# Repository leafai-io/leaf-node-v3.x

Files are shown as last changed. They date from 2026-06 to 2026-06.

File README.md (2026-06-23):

# Leaf Node 3.1

Leaf AI is an independent, open-source project. If you find it useful, you can support its continued development at [Leaf AI Support](https://leafai.io/support.html).

The Leaf Node is an open-source environmental 
monitoring and control device built on the 
ESP32-S3. It reads sensor data, publishes it 
over MQTT, and can trigger actuators — allowing 
you to monitor conditions and directly control 
connected devices such as lights, fans, pumps 
and valves. Configuration is handled wirelessly 
via BLE, making it a self-contained building 
block for precision agriculture and 
environmental monitoring and automation systems.

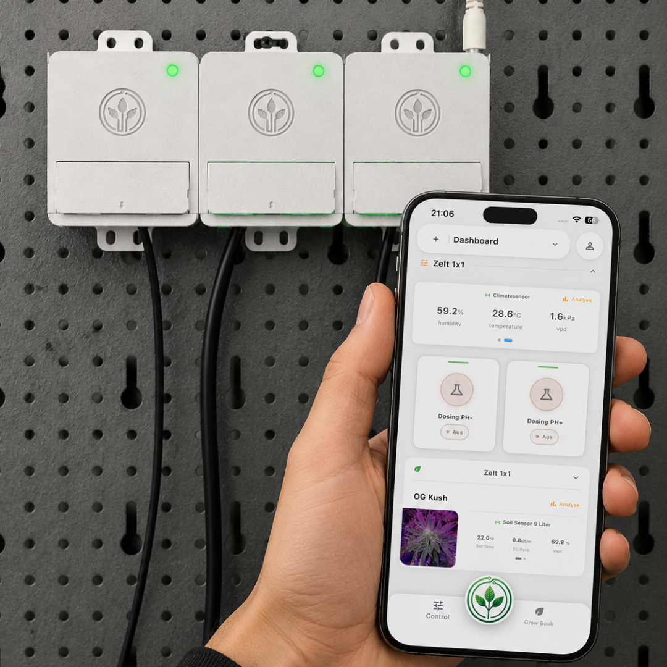
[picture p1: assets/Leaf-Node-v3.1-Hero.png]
Leaf Node


<!-- Hero image: replace the path below with your device photo -->
<!-- ![Leaf Node device photo](assets/hero.jpg) -->

---

## Philosophy

Leaf Node is built around one principle: **it should just work.** From first flash to live sensor data in minutes — simple enough for a grower to deploy in the field, open enough for a developer to extend and build on. No unnecessary complexity, no steep learning curve.

---

## Features

- **Multi-protocol sensor support** — I2C, RS485, SDI-12, OneWire on a single board
- **MQTT telemetry** — publishes sensor data and heartbeats, receives commands
- **OTA firmware updates** — triggered via MQTT command, no physical access needed
- **BLE provisioning** — initial Wi-Fi and MQTT setup from the companion app, no serial cable required
- **Scheduling** — DAC and actuator outputs can be programmed on a time-based schedule
- **Smart control** — MOSFET and relay outputs with duration-based switching
- **Node chaining** — UART-based daisy-chain for multi-node deployments
- **Watchdog & health monitoring** — automatic recovery with exponential backoff on sensor errors
- **Factory mode** — serial-console provisioning for production flashing

---

## Hardware

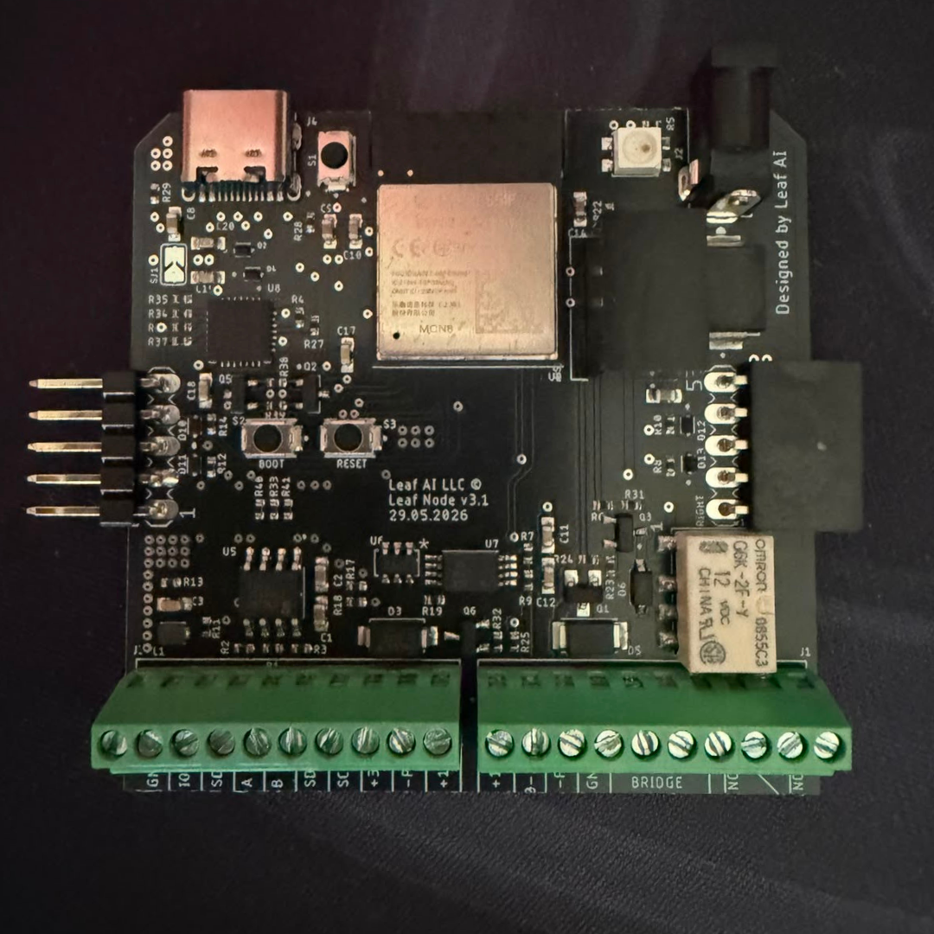
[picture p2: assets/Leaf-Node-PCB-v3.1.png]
Leaf Node PCB


### Overview

| Component | Details |
|---|---|
| MCU | ESP32-S3 |
| Status LED | WS2812B addressable RGB (v3) |
| RS485 | Half-duplex, DE/RE controlled |
| I2C | SDA GPIO8, SCL GPIO9 |
| SDI-12 | GPIO12 (shared with OneWire via hardware bridge) |
| OneWire | GPIO12 |
| Actuators | MOSFET (GPIO36), Relay (GPIO38), DAC (MCP4725 via I2C) |
| PWM | GPIO2 (1 kHz, 10-bit) + MOSFET gate (5 kHz, 10-bit) |

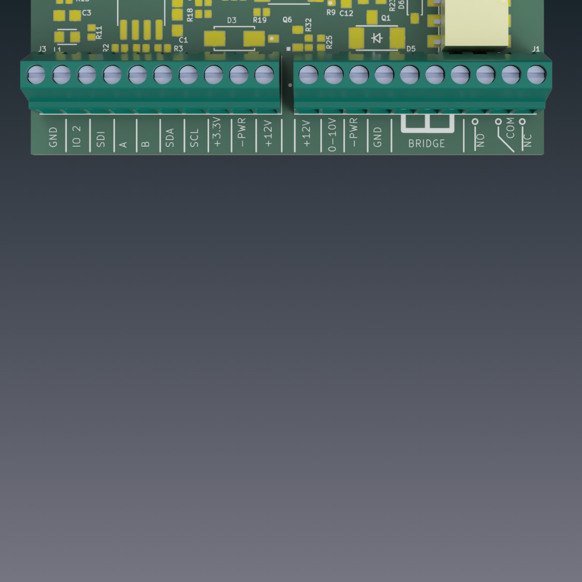
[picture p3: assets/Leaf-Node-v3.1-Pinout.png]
Leaf Node Pinout


### Supported Sensors

| Sensor | Interface | Wiring | Measurement |
|---|---|---|---|
| SHT31  | I2C (0x44) | +3.3V · GND · SDA · SCL | Temperature, Humidity |
| EZO pH | I2C (0x63) | +3.3V · GND · SDA · SCL | pH |
| EZO EC | I2C (0x64) | +3.3V · GND · SDA · SCL | Electrical Conductivity |
| TEROS 12 | SDI-12 | +3.3V · GND · SDI-12 | Soil moisture, temperature, EC |
| DS18B20 | OneWire | +3.3V · GND · Need Modification | Temperature |
| SLT5007 | RS485 | +3.3V · GND · A · B | VWC, Bulk EC, Soil temperature, Pore EC |
| CWT-PSS | RS485 | +12V · GND · A · B | PAR (Photosynthetically Active Radiation) |
| LEAFTHSN | RS485 | +12V · GND · A · B | Leaf wetness, Leaf temperature |
| CWT-SoilTHS | RS485 | +12V · GND · A · B | VWC, Soil temperature |
| CWT-THXXS | RS485 | +12V · GND · A · B | Air temperature, Humidity, VPD |

### Actuators

| Actuator | GPIO / Interface | Wiring | Typical Use |
|---|---|---|---|
| MOSFET | GPIO36 | +12V · -PWR | Pumps, fans, DC loads |
| Relay | GPIO38 | COM · NO · NC | AC/DC switching, high-current loads |
| DAC (MCP4725) | I2C (0x60) | 0-10V · GND | Analog 0–5 V output (e.g. dosing pumps) |
| PWM | GPIO2 | IO2 · GND | Variable speed / dimming control |

### PCB & Enclosure

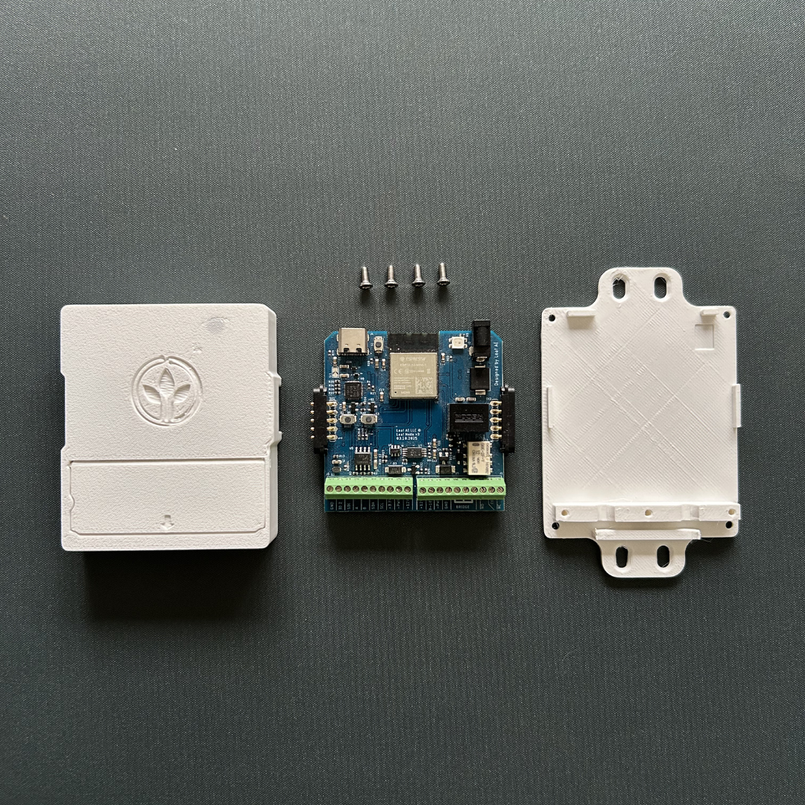
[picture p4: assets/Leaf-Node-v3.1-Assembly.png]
Leaf Node Assembly


- KiCad project: [hardware/pcb/kiCad/](hardware/pcb/kiCad/)
- Enclosure STL/STEP files: [hardware/enclosure/](hardware/enclosure/)
---

## Getting Started

### Option A — Web Flasher (recommended)

No toolchain required. Works directly in Chrome/Edge.

1. **Get the hardware** — order a ready-to-use Leaf Node at [Build Your Leaf Node](https://leafai.io/build-node.html), or fabricate your own PCB from the [KiCad files](hardware/pcb/kiCad/)
2. Open the **[Leaf AI Firmware Flasher](https://leafai.io/firmware-flasher.html)** and follow the on-screen steps
3. Open the Leaf AI app, tap **Add Device**, and provision Wi-Fi via BLE

That's it — the node connects to the Leaf AI backend and starts publishing sensor data.

> A free Leaf AI account is required to use the app. Sign up directly in the Leaf AI app.

---

### Option B — Build from source (PlatformIO)

For developers who want to modify or extend the firmware.

**Prerequisites:** [PlatformIO](https://platformio.org/) (CLI or VS Code extension)

#### 1. Assemble the hardware

Fabricate the PCB from the files in [hardware/pcb/](hardware/pcb/) and wire your sensors according to the pin table above.

#### 2. Flash the firmware

> **First flash:** Use the **[Leaf AI Firmware Flasher](https://leafai.io/firmware-flasher.html)** for the initial flash. It writes a compatible serial number to the device that is required for communication with the Leaf AI app. Subsequent builds can be uploaded via PlatformIO.

```bash
git clone https://github.com/leafai-io/leaf-node-v3.1.git
cd leaf-node-v3.1
pio run --target upload
```

Monitor serial output (115200 baud):

```bash
pio device monitor
```

#### 3. Provision via BLE

Open the Leaf AI app, tap **Add Device**, and follow the on-screen steps to configure Wi-Fi and link your account.

---

## Using with the App

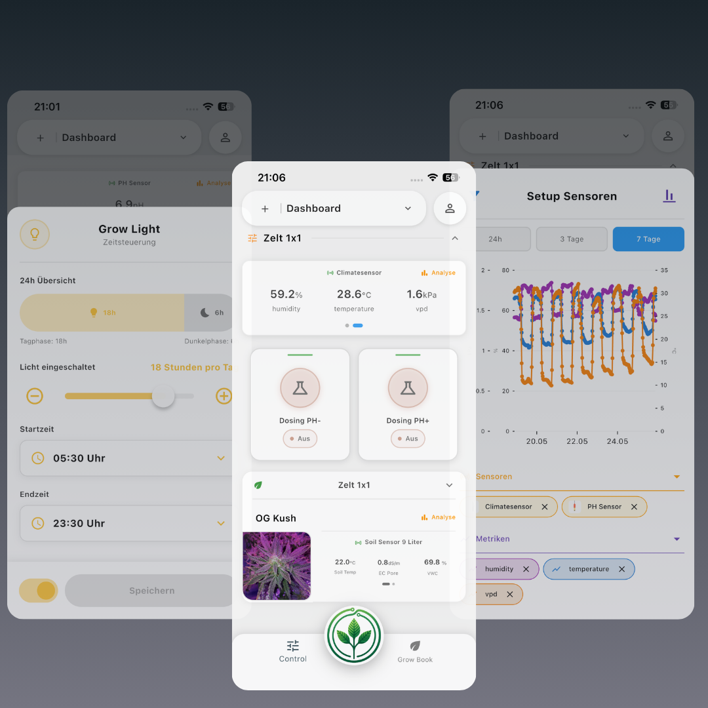
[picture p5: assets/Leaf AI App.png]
Leaf AI App


Once your Leaf Node is provisioned, open the Leaf AI app to view live sensor readings, configure schedules, and control actuators — all from your phone.

---

## License

This project uses two open-source licences depending on what you are working with:

| Component | Licence |
|---|---|
| Firmware / Software | [GNU AGPL-3.0](licenses/LICENSE-SOFTWARE) |
| Hardware (PCB, enclosure) | [CERN-OHL-S v2](licenses/LICENSE-HARDWARE) |

**Software (AGPL-3.0):** You can use, modify, and distribute the firmware freely, but any modified version you run as a networked service must also be released under the same licence.

**Hardware (CERN-OHL-S v2):** You can study, modify, and manufacture the hardware freely, but any modified design you distribute or produce must be released under the same licence with complete source files.

**If you create a fork, we'd love to hear about it.** Open an issue or send us a message so we can showcase your project and potentially integrate useful improvements.

---

## Support

Leaf AI is an independent, open-source project. If you find it useful, you can support its continued development at [Leaf AI Support](https://leafai.io/support.html).

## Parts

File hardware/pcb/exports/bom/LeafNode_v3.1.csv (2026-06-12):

Qty | Value | Device | Package | Parts | Description
2 |  | MA05-1 | MA05-1 | LEFT, RIGHT | PIN HEADER
1 |  | SOLDERJUMPER | SOLDERJUMPER_ARROW_NOPASTE | SJ1 | SMD Solder JUMPER
3 | 0R | R-EU_R0402 | R0402 | R4, R5, R27 | RESISTOR, European symbol
4 | 100 | R-EU_R0402 | R0402 | R8, R10, R12, R14 | RESISTOR, European symbol
1 | 100k | R-EU_R0402 | R0402 | R13 | RESISTOR, European symbol
6 | 100nF | C-EUC0603 | C0603 | C10, C11, C12, C17, C18, C19 | CAPACITOR, European symbol
13 | 10k | R-EU_R0402 | R0402 | R17, R18, R19, R22, R23, R31, R32, R33, R37, R38, R39, R40, R41 | RESISTOR, European symbol
6 | 10uF | C-EUC0603 | C0603 | C1, C2, C4, C5, C8, C9 | CAPACITOR, European symbol
1 | 120 | R-EU_R0402 | R0402 | R1 | RESISTOR, European symbol
2 | 1725737 | 1725737 | PHOENIX_1725737 | J1, J3 | Check availability
1 | 1N4148W | 1N4148W | SODFL3816X120N | D6 | Check availability
4 | 1k | R-EU_R0402 | R0402 | R6, R7, R24, R25 | RESISTOR, European symbol
1 | 1uF | C-EUC0603 | C0603 | C14 | CAPACITOR, European symbol
2 | 20k | R-EU_R0402 | R0402 | R2, R3 | RESISTOR, European symbol
1 | 220pF | C-EUC0603 | C0603 | C3 | CAPACITOR, European symbol
1 | 22k1 | R-EU_R0402 | R0402 | R35 | RESISTOR, European symbol
1 | 2k | R-EU_R0402 | R0402 | R36 | RESISTOR, European symbol
1 | 2k1 | R-EU_R0402 | R0402 | R9 | RESISTOR, European symbol
1 | 4,7uF | C-EUC0603 | C0603 | C20 | CAPACITOR, European symbol
1 | 47k5 | R-EU_R0402 | R0402 | R34 | RESISTOR, European symbol
1 | 510 | R-EU_R0402 | R0402 | R11 | RESISTOR, European symbol
2 | 5k1 | R-EU_R0402 | R0402 | R28, R29 | RESISTOR, European symbol
1 | BOOT | SKRKAEE010 | SKRK | S2 | Tactile Switches 3.9x2.9x2.0mm 160gf Packaging Temp 60oC
1 | CP2102 | CP2102 | QFN50P500X500X100-29N | U8 | Check availability
1 | CSP-USC16-TR | CSP-USC16-TR | VALCON_CSP-USC16-TR | J4 | Check availability
1 | ESP32-S3-MINI-1-N8 | ESP32-S3-MINI-1-N8 | XCVR_ESP32-S3-MINI-1-N8 | U2 | Check availability
1 | G6K-2F-Y-DC12 | G6K-2F-Y-DC12 | G6K | U16 | Check availability
1 | IRLML6344 | IRLML6344 | SOT23 | Q1 | Check availability
6 | LESD5D5.0CT1G | LESD5D5.0CT1G | TVS_LESD5D5.0CT1G | D2, D4, D10, D11, D12, D13 | Check availability
1 | LM358PW | LM358PW | SOP65P640X120-8N | U7 | Check availability
1 | LQH2MCN100M52L | LQH2MCN100M52L | IND_LQH2MCN100M52L | L1 | Check availability
1 | MAX485ESA+T | MAX485ESA+T | SOIC127P600X175-8N | U5 | Check availability
1 | MBRS540T3G | MBRS540T3G | DIOM7959X261N | D1 | Check availability
1 | MCP4725A1T-E/CH | MCP4725A1T-E/CH | SOT23-6 | U6 | Check availability
1 | PJ-018H | PJ-018H | CUI_PJ-018H | J2 | Check availability
1 | PMEG3030EP | PMEG3030EP | SOD_128 | D5 | Check availability
1 | R-78E3.3-1.0 | R-78E3.3-1.0 | CONV_R-78E3.3-1.0 | PS1 | Check availability
1 | RESET | SKRKAEE010 | SKRK | S3 | Tactile Switches 3.9x2.9x2.0mm 160gf Packaging Temp 60oC
2 | SI2302DS | SI2302DS | SOT23-3/TO-236AB | Q3, Q6 | Check availability
1 | SK68XXMINI-HS | SK68XXMINI-HS | 3535 | D7
1 | SKRKAEE010 | SKRKAEE010 | SKRK | S1 | Tactile Switches 3.9x2.9x2.0mm 160gf Packaging Temp 60oC
1 | SS14 | SS14 | DIOM4325X250N | D3 | Check availability
2 | SS8050-G | SS8050-G | TRANS_SS8050-G | Q2, Q5 | Check availability
7 | TPTP13R | TPTP13R | TP13R | D+, D-, EN, IO0, IO39, RXD, TXD | Test pad

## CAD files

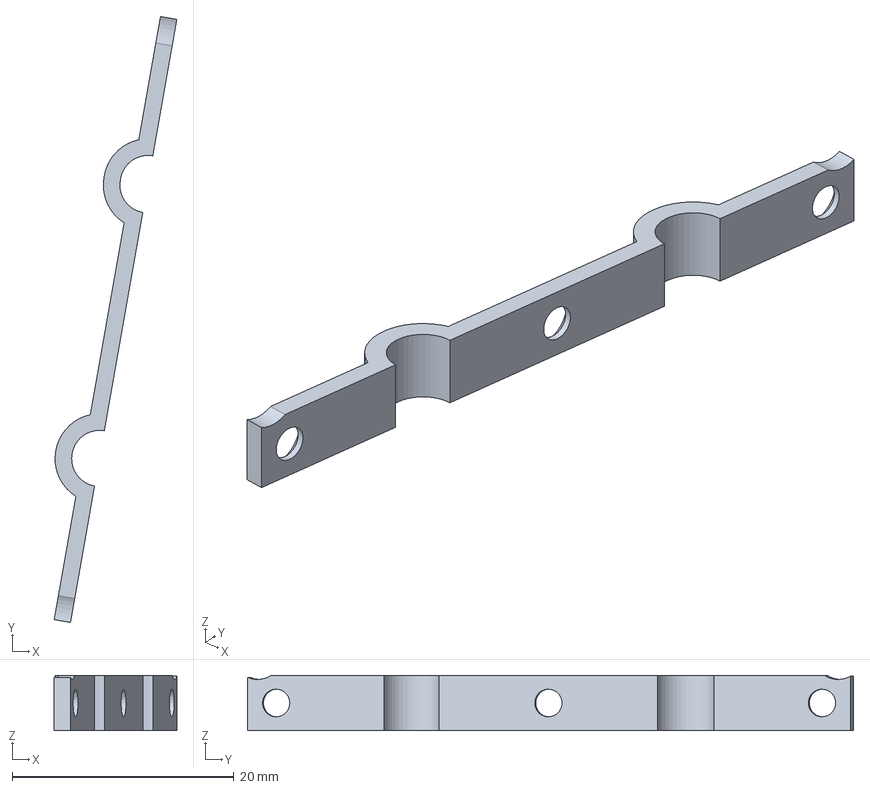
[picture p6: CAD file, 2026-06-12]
hardware/enclosure/3dPrinting/Leaf-Node-Cable-Fixation.3mf
11.1 x 54.7 x 5.00 mm

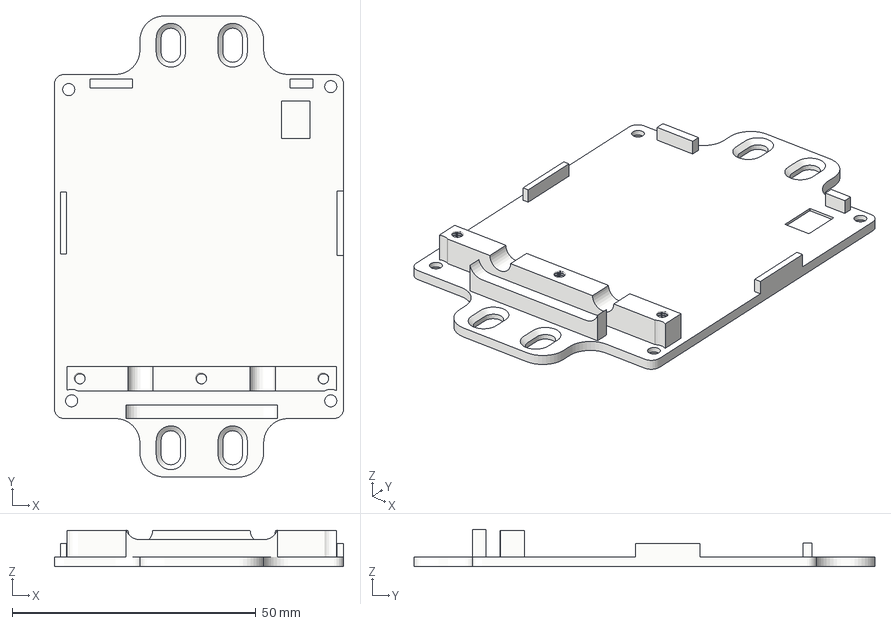
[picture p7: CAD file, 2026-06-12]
hardware/enclosure/3dPrinting/Leaf-Node-Basic-Cover.3mf
59.4 x 94.7 x 7.68 mm

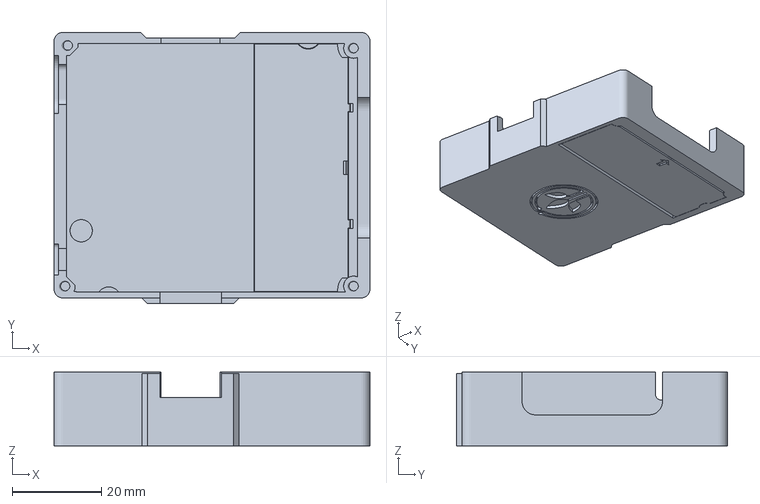
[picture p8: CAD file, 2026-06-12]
hardware/enclosure/3dPrinting/Leaf-Node-Body.3mf
70.7 x 60.7 x 16.4 mm

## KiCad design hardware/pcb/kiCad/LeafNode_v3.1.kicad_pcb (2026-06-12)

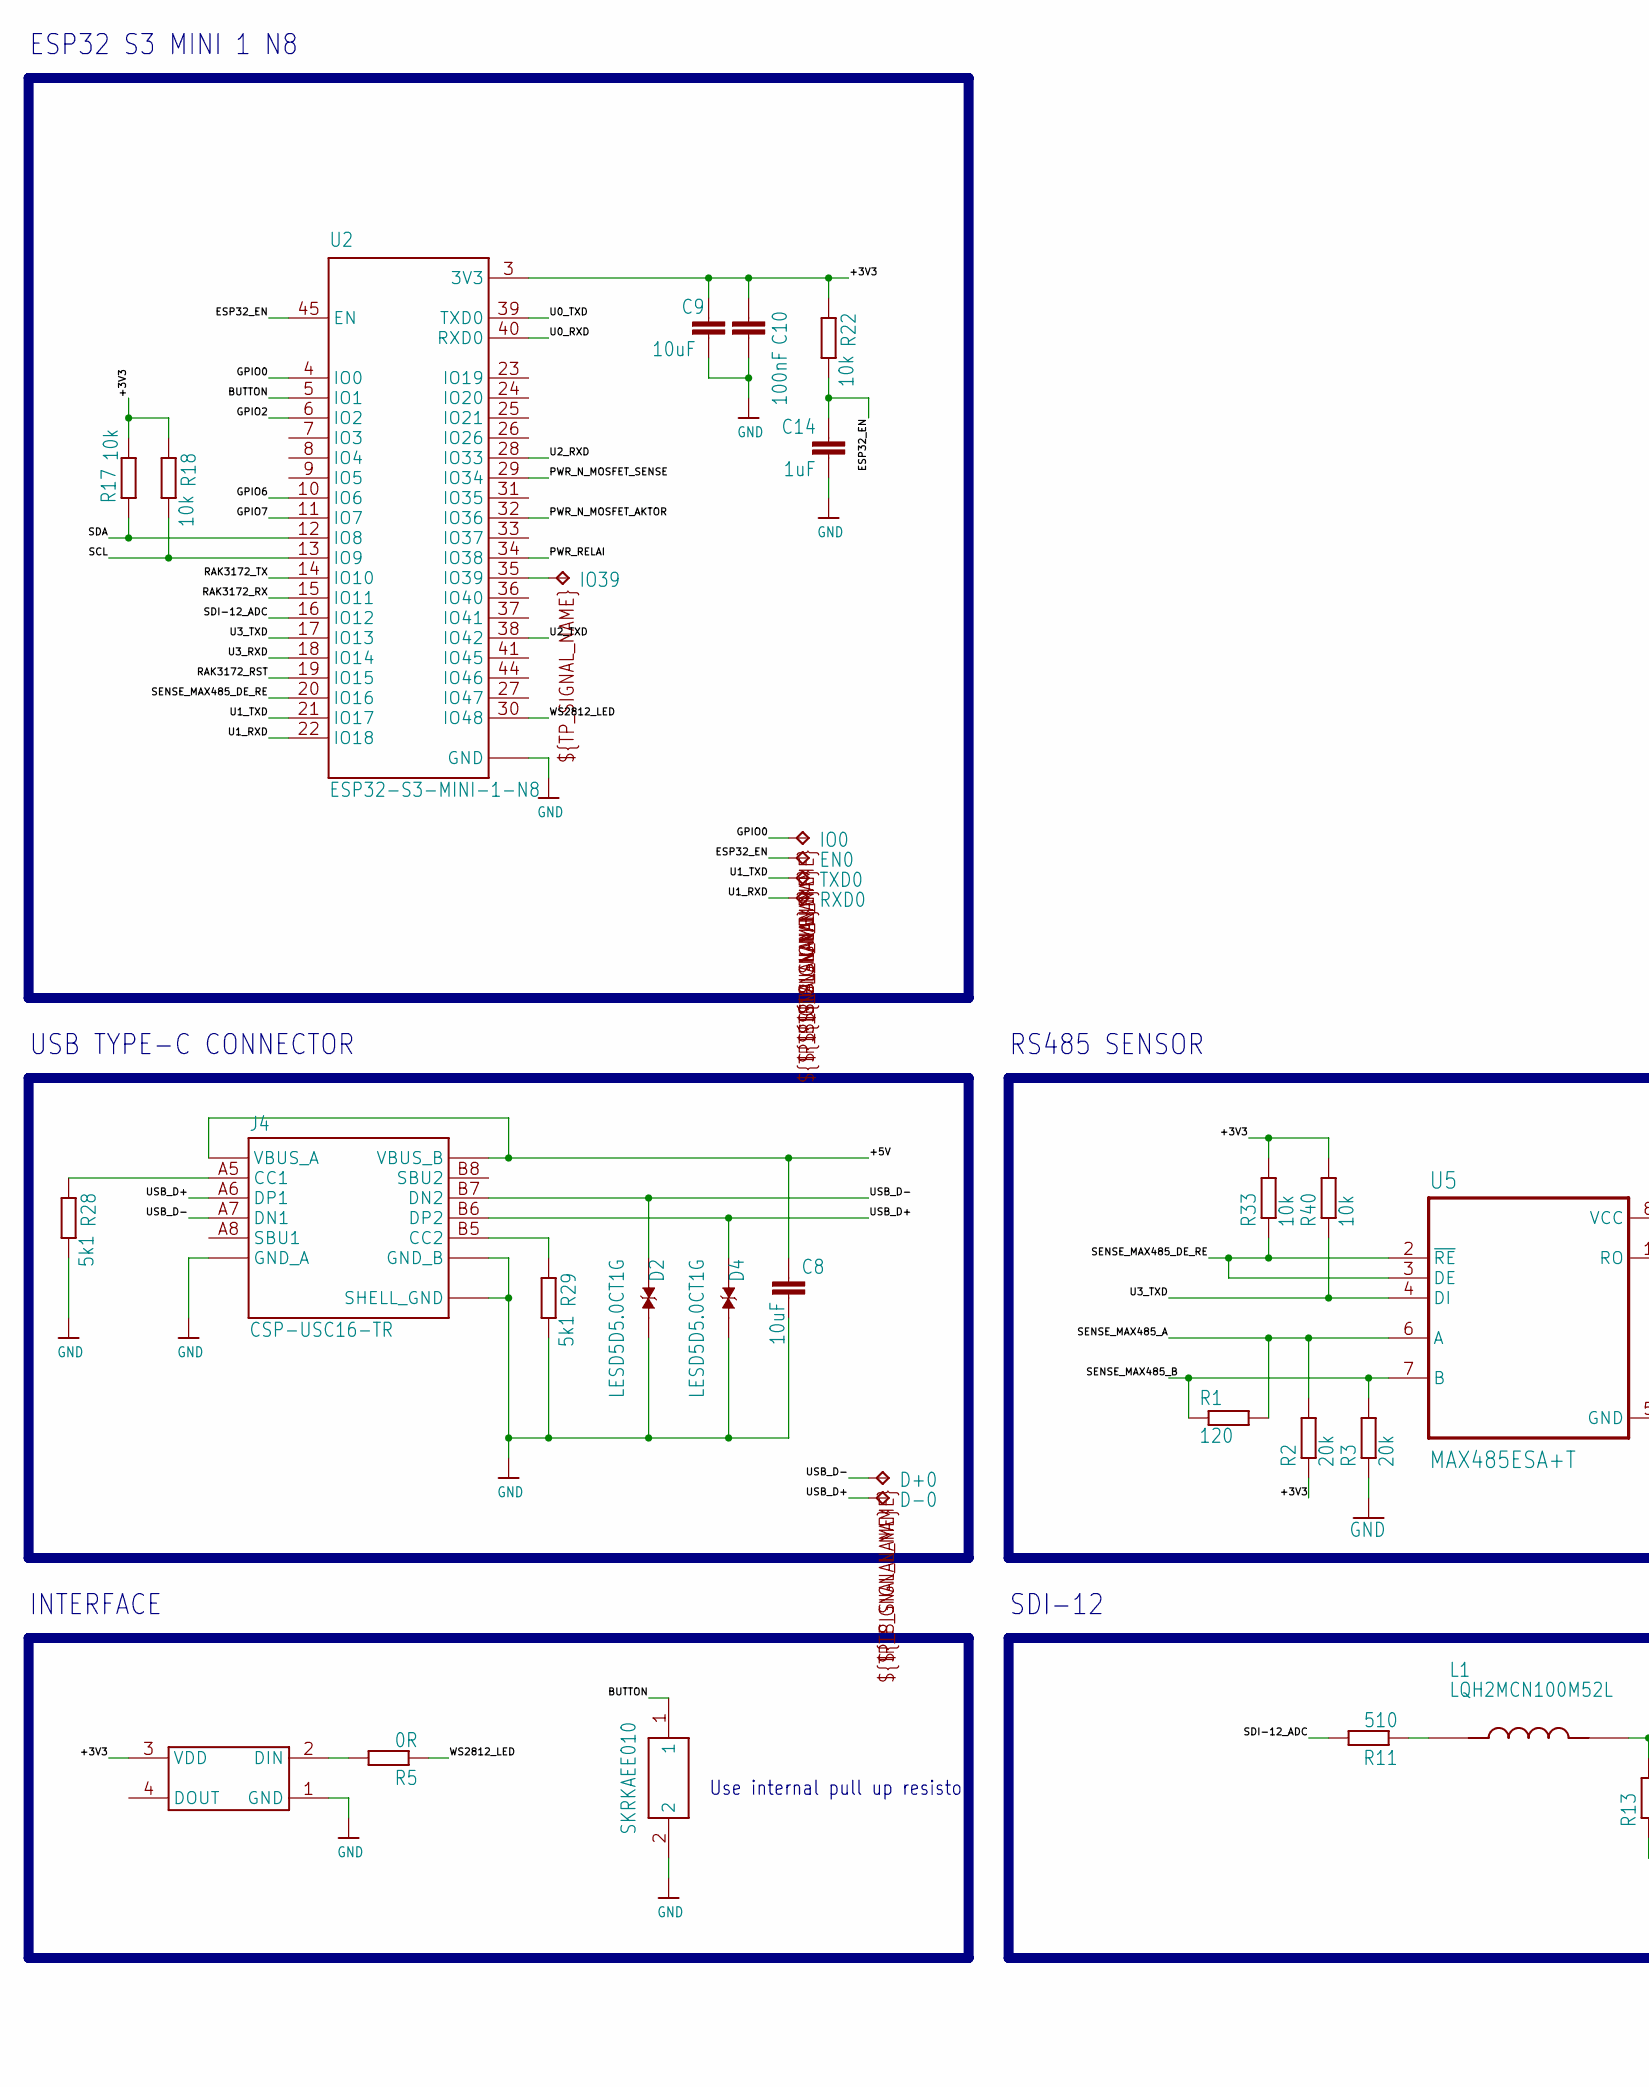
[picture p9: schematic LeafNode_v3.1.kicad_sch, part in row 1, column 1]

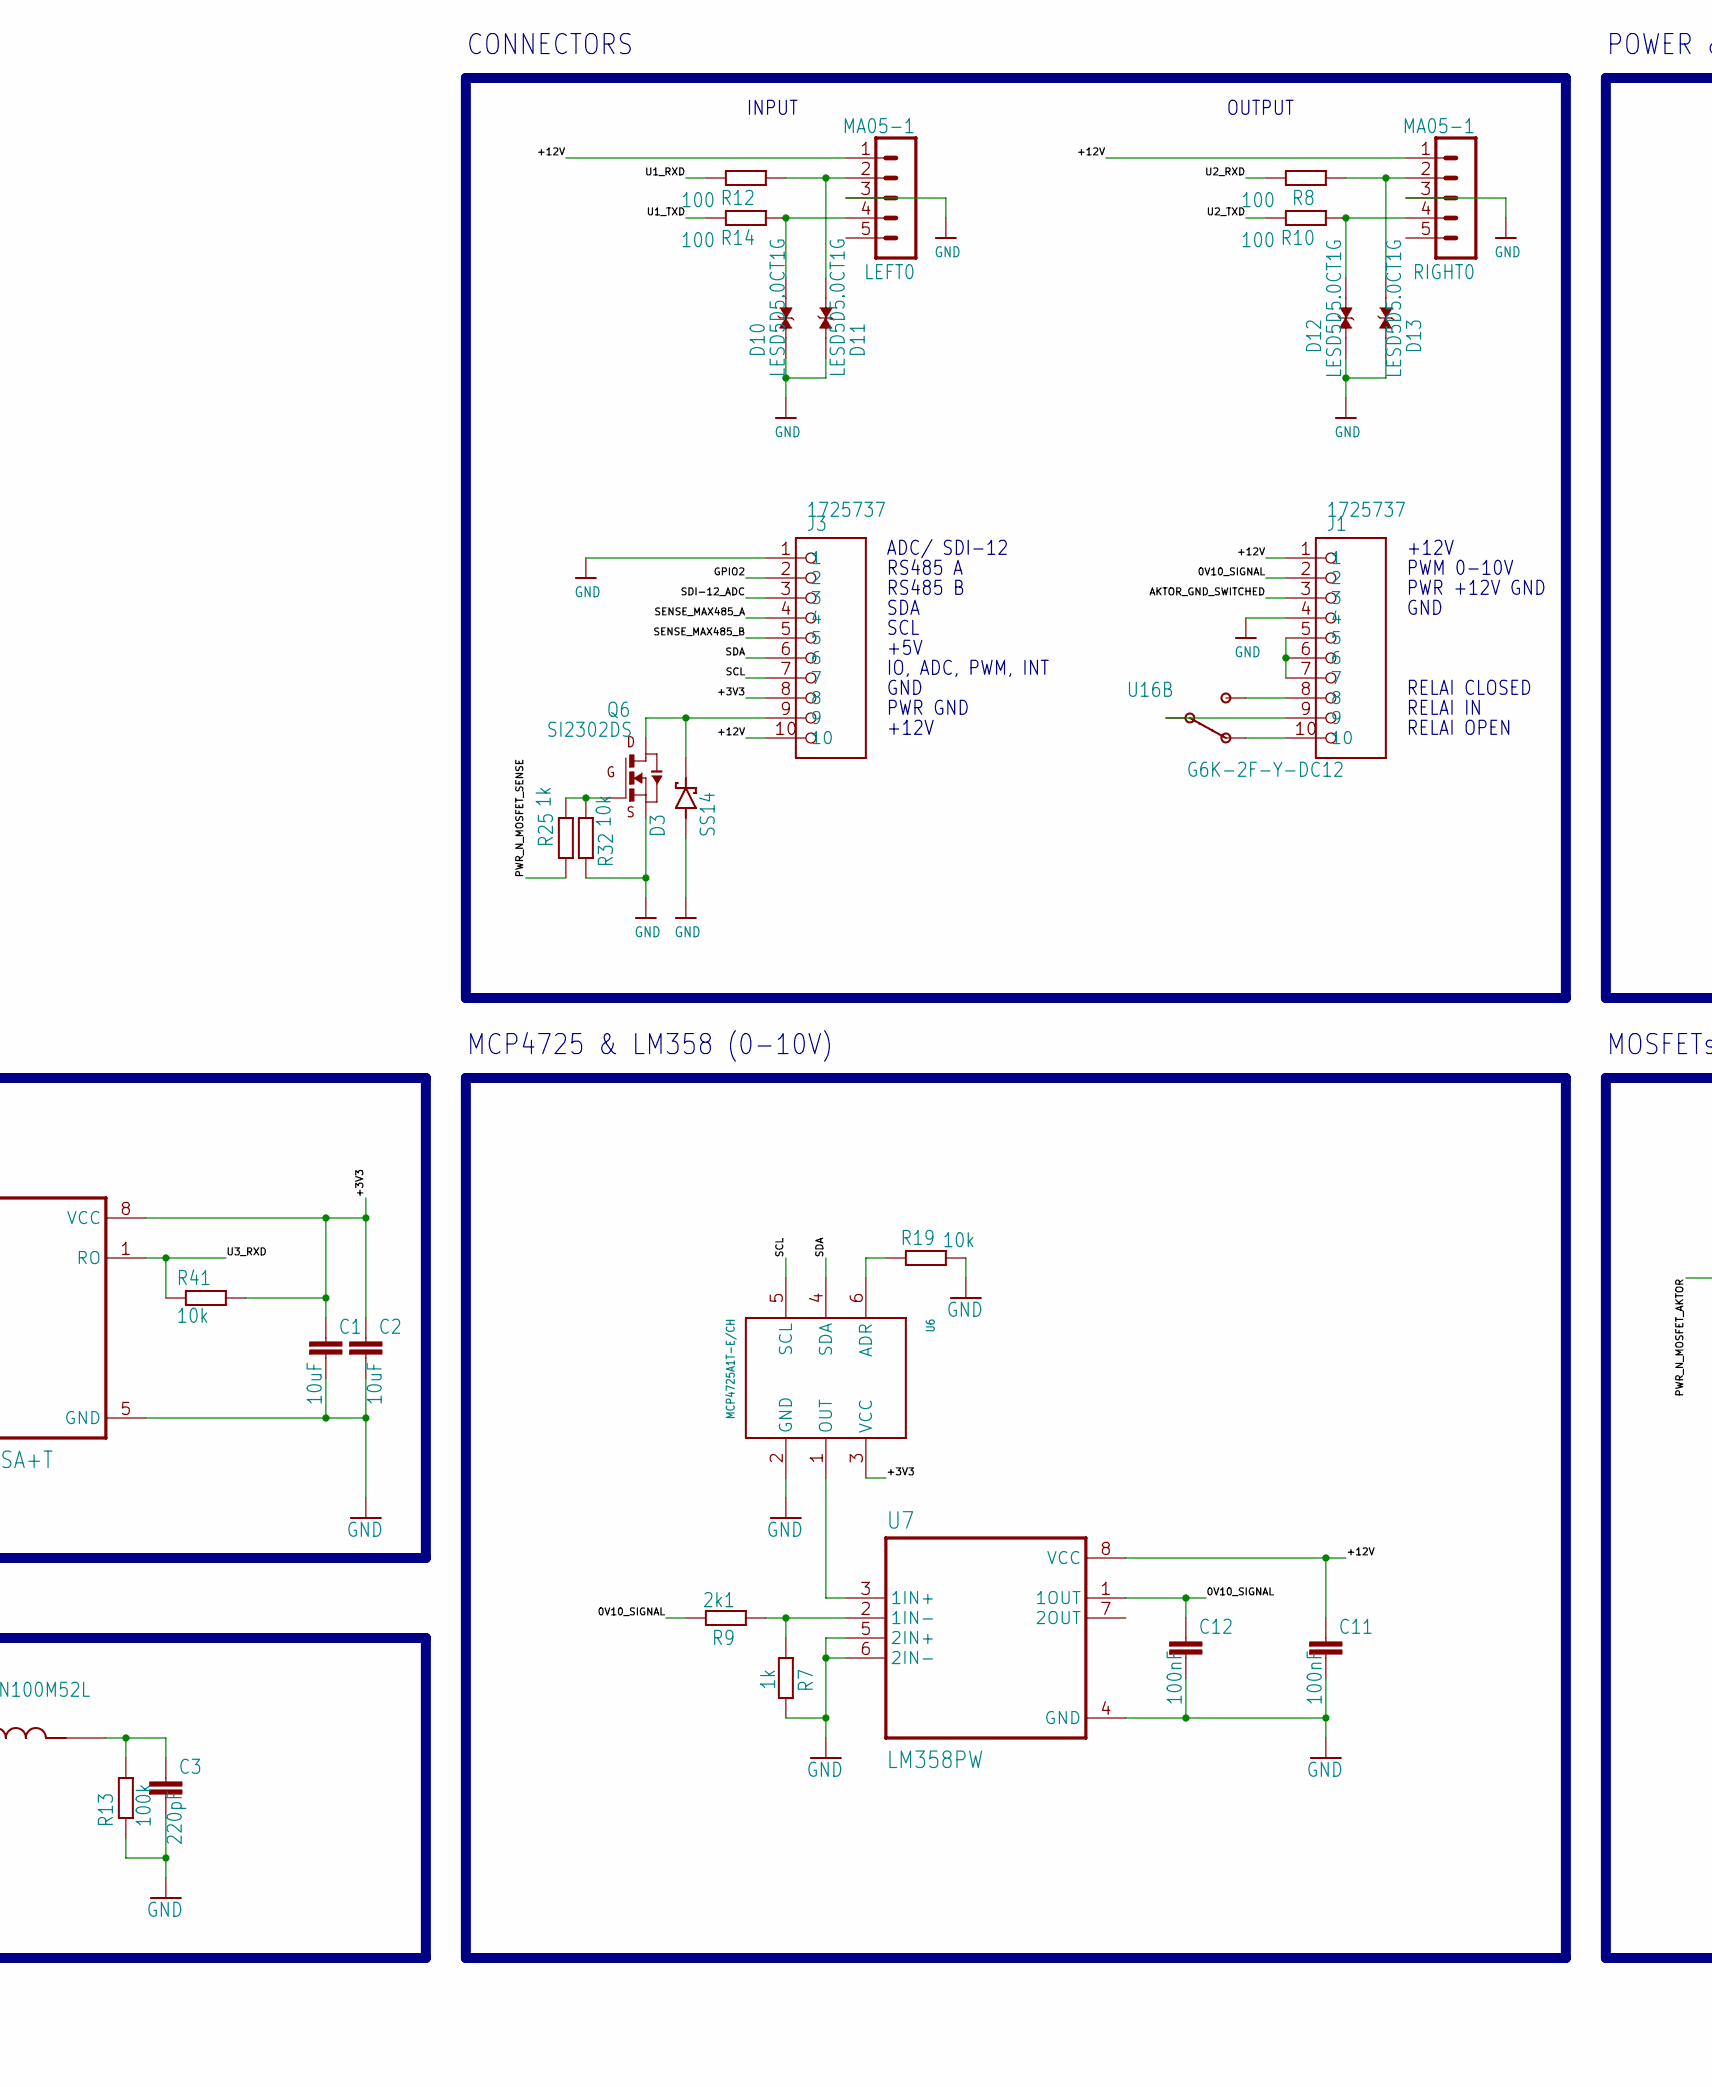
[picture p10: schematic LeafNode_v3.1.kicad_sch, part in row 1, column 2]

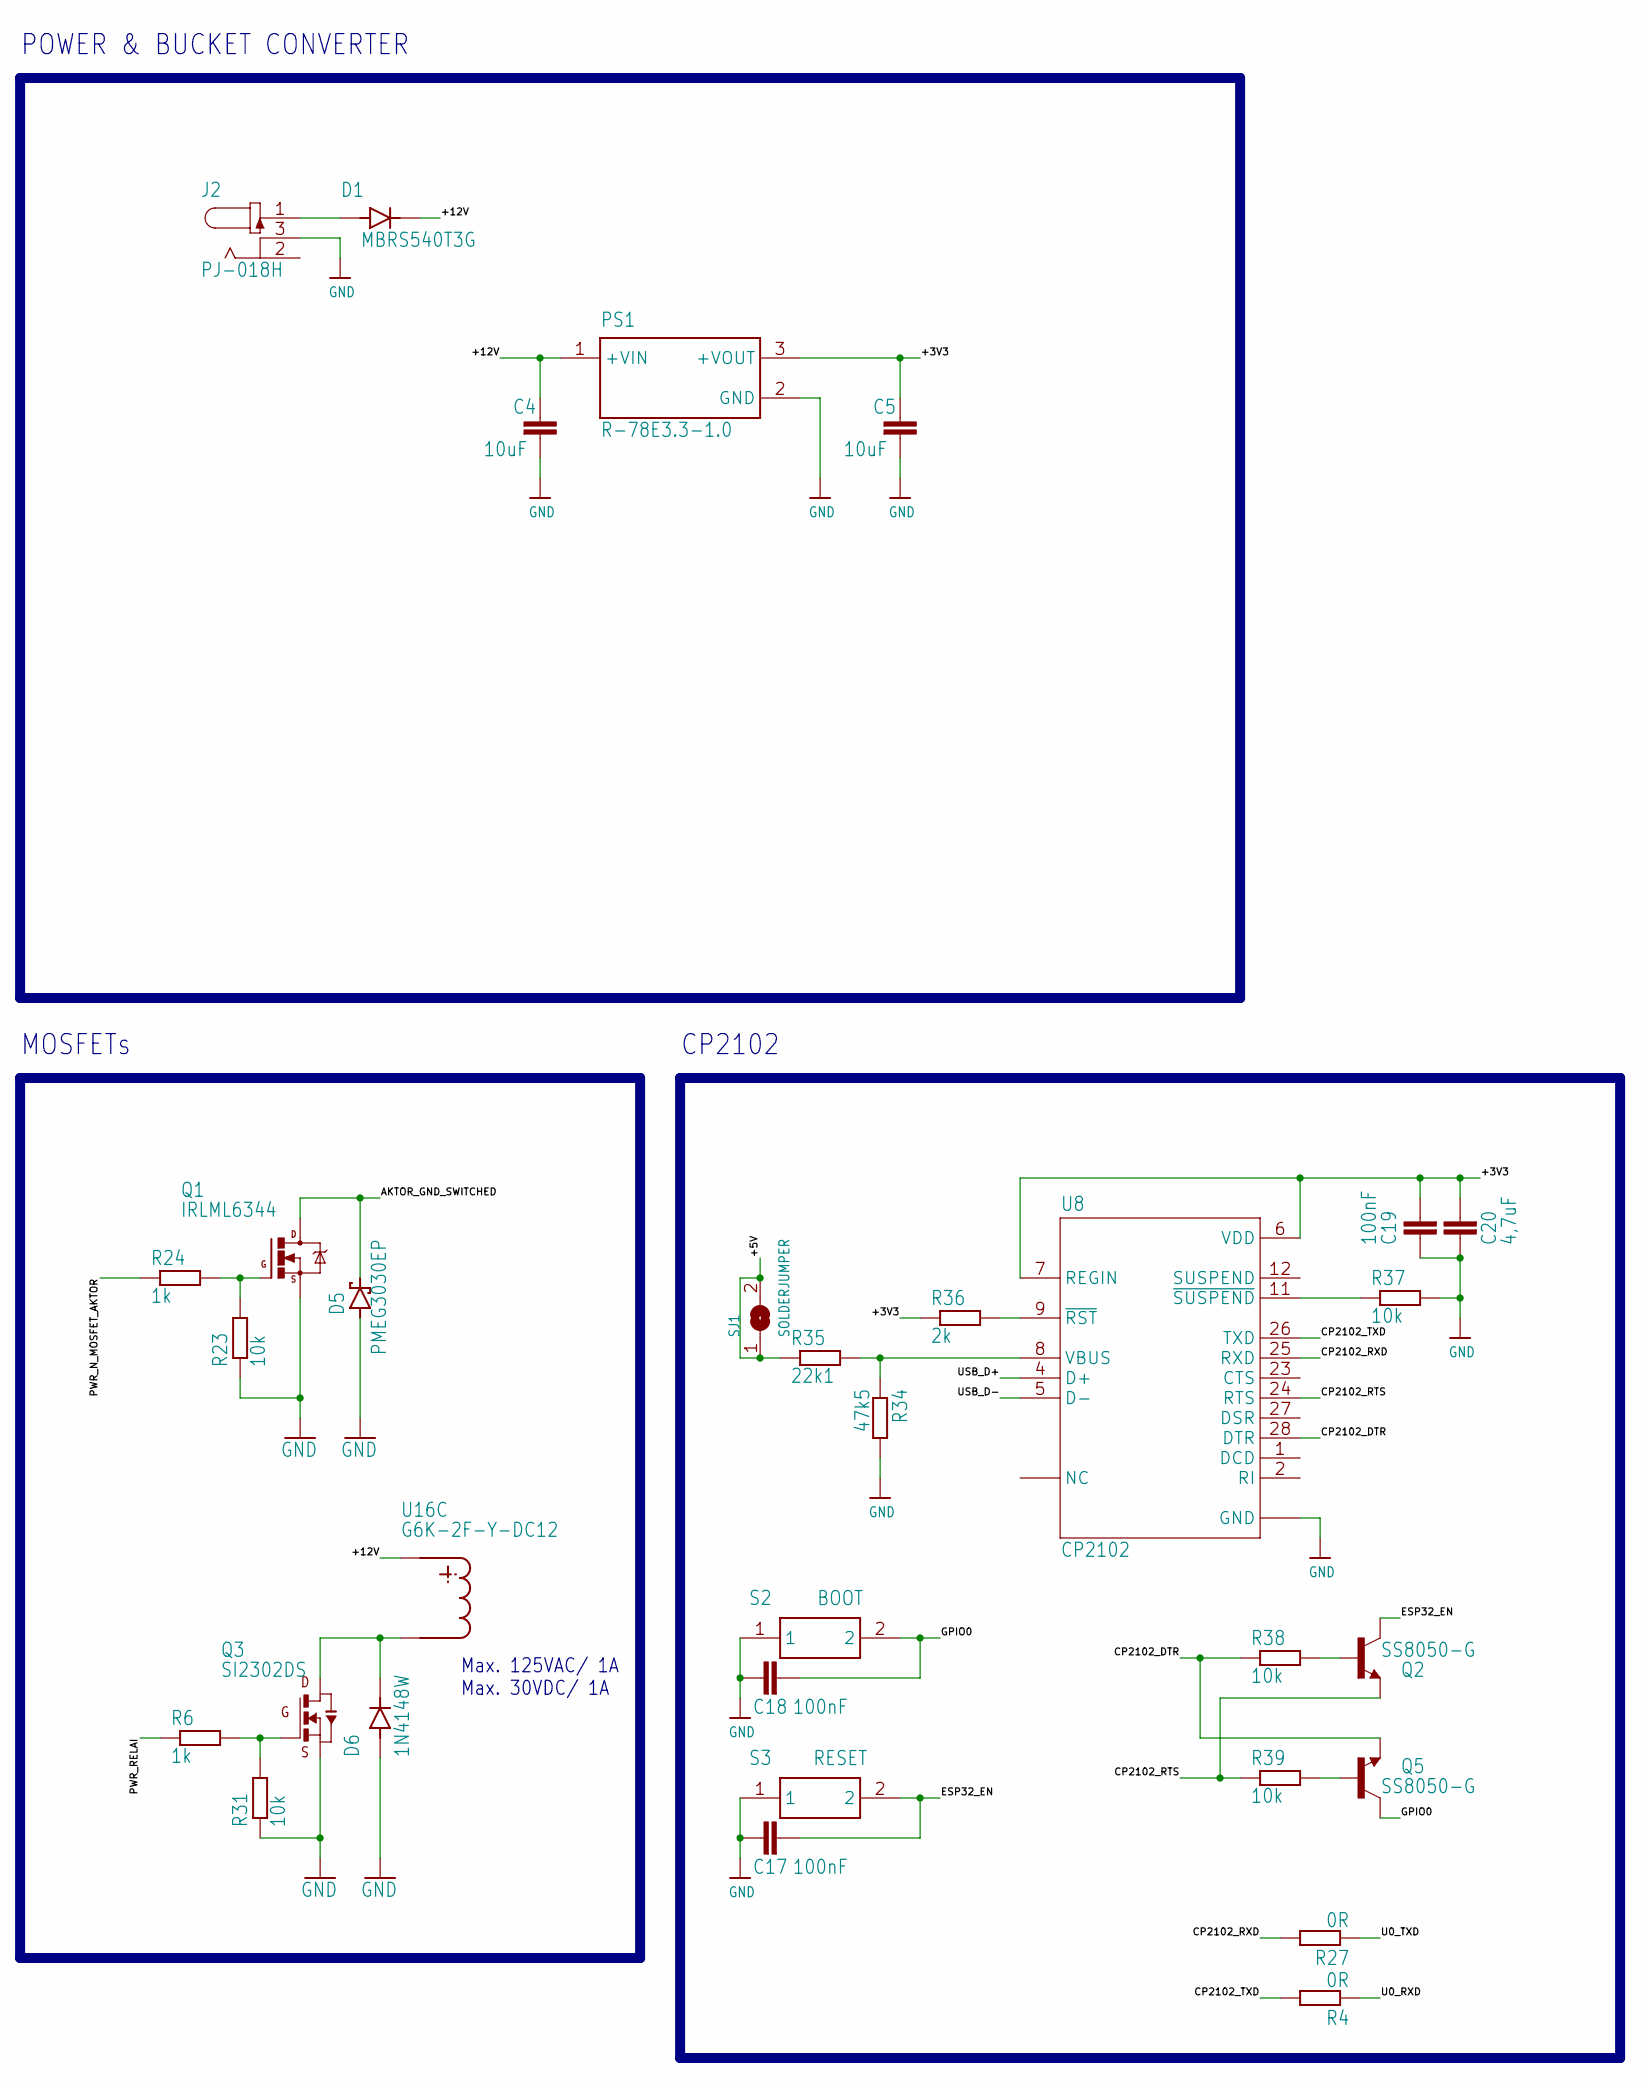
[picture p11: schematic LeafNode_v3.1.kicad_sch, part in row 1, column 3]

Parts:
C1, C2, C4, C5, C8, C9: 10uF; C0603
C3: 220pF; C0603
C10, C11, C12, C17, C18, C19: 100nF; C0603
C14: 1uF; C0603
C20: 4,7uF; C0603
D1: MBRS540T3G; DIOM7959X261N
D2, D4, D10, D11, D12, D13: LESD5D5.0CT1G; TVS_LESD5D5.0CT1G
D3: SS14; DIOM4325X250N
D5: PMEG3030EP; SOD_128
D6: 1N4148W; SODFL3816X120N
D7: SK68XXMINI-HS; 3535
D+0: TPTP13R; TP13R
D-0: TPTP13R; TP13R
EN0: TPTP13R; TP13R
IO0, IO39: TPTP13R; TP13R
J1, J3: 1725737; PHOENIX_1725737
J2: PJ-018H; CUI_PJ-018H
J4: CSP-USC16-TR; VALCON_CSP-USC16-TR
L1: LQH2MCN100M52L; IND_LQH2MCN100M52L
LEFT0: MA05-1
PS1: R-78E3.3-1.0; CONV_R-78E3.3-1.0
Q1: IRLML6344; SOT23
Q2, Q5: SS8050-G; TRANS_SS8050-G
Q3, Q6: SI2302DS; SOT23-3_TO-236AB
R1: 120; R0402
R2, R3: 20k; R0402
R4, R5, R27: 0R; R0402
R6, R7, R24, R25: 1k; R0402
R8, R10, R12, R14: 100; R0402
R9: 2k1; R0402
R11: 510; R0402
R13: 100k; R0402
R17, R18, R19, R22, R23, R31, R32, R33, R37, R38, R39, R40, R41: 10k; R0402
R28, R29: 5k1; R0402
R34: 47k5; R0402
R35: 22k1; R0402
R36: 2k; R0402
RIGHT0: MA05-1
RXD0: TPTP13R; TP13R
S1: SKRKAEE010; SKRK
S2: BOOT; SKRK
S3: RESET; SKRK
SJ1: SOLDERJUMPER; SOLDERJUMPER_ARROW_NOPASTE
TXD0: TPTP13R; TP13R
U2: ESP32-S3-MINI-1-N8; XCVR_ESP32-S3-MINI-1-N8
U5: MAX485ESA+T; SOIC127P600X175-8N
U6: MCP4725A1T-E/CH; SOT23-6
U7: LM358PW; SOP65P640X120-8N
U8: CP2102; QFN50P500X500X100-29N
U16: G6K-2F-Y-DC12; G6K

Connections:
0V10_SIGNAL: C12.1, J1.2, R9.2, U7.1 (1OUT)
+3V3: C1.1, C2.1, C5.1, C9.1, C10.1, C19.2, C20.2, D7.3 (VDD), J3.8, PS1.3 (+VOUT), R2.1, R17.1, R18.2, R22.2, R33.2, R36.1, R40.2, R41.2, U2.3 (3V3), U5.8 (VCC), U6.3 (VCC), U8.6 (VDD), U8.7 (REGIN)
+5V: C8.1, J4.A4 (VBUS_A), J4.A9 (VBUS_A), J4.B4 (VBUS_B), J4.B9 (VBUS_B), R35.1, SJ1.1, SJ1.2
+12V: C4.1, C11.1, D1.1 (C), J1.1, J3.10, LEFT0.1, PS1.1 (+VIN), RIGHT0.1, U7.8 (VCC), U16.1 (COIL+)
AKTOR_GND_SWITCHED: D5.C, J1.3, Q1.3 (D)
BUTTON: S1.1, U2.5 (IO1)
CP2102_DTR: Q5.2 (E), R38.1, U8.28 (DTR)
CP2102_RTS: Q2.2 (E), R39.1, U8.24 (RTS)
CP2102_RXD: R27.2, U8.25 (RXD)
CP2102_TXD: R4.2, U8.26 (TXD)
ESP32_EN: C14.1, C17.2, EN0.TP, Q2.3 (C), R22.1, S3.2, U2.45 (EN)
GND: C1.2, C2.2, C3.2, C4.2, C5.2, C8.2, C9.2, C10.2, C11.2, C12.2, C14.2, C17.1, C18.1, C19.1, C20.1, D2.2, D3.A, D4.2, D5.A, D6.A, D7.1 (GND), D10.1, D11.1, D12.2, D13.2, J1.4, J2.3, J3.1, J4.A1 (GND_A), J4.A12 (GND_A), J4.B1 (GND_B), J4.B12 (GND_B), J4.S1 (SHELL_GND), J4.S2 (SHELL_GND), J4.S3 (SHELL_GND), J4.S4 (SHELL_GND), LEFT0.3, PS1.2 (GND), Q1.2 (S), Q3.2 (S), Q6.2 (S), R3.1, R7.2, R13.1, R19.1, R23.1, R28.1, R29.1, R31.1, R32.1, R34.2, R37.2, RIGHT0.3, S1.2, S2.1, S3.1, U2.1 (GND), U2.2 (GND), U2.42 (GND), U2.43 (GND), U2.46 (GND), U2.47 (GND), U2.48 (GND), U2.49 (GND), U2.50 (GND), U2.51 (GND), U2.52 (GND), U2.53 (GND), U2.54 (GND), U2.55 (GND), U2.56 (GND), U2.57 (GND), U2.58 (GND), U2.59 (GND), U2.60 (GND), U2.61 (GND), U2.61_1 (GND), U2.61_2 (GND), U2.61_3 (GND), U2.61_4 (GND), U2.61_5 (GND), U2.61_6 (GND), U2.61_7 (GND), U2.61_8 (GND), U2.62 (GND), U2.63 (GND), U2.64 (GND), U2.65 (GND), U5.5 (GND), U6.2 (GND), U7.4 (GND), U7.5 (2IN+), U7.6 (2IN-), U8.3 (GND), U8.29 (GND)
GPIO0: C18.2, IO0.TP, Q5.3 (C), S2.2, U2.4 (IO0)
GPIO2: J3.2, U2.6 (IO2)
GPIO6: U2.10 (IO6)
GPIO7: U2.11 (IO7)
unnamed: U6.1 (OUT), U7.3 (1IN+)
unnamed: R7.1, R9.1, U7.2 (1IN-)
unnamed: J1.5, J1.6, J1.7
unnamed: R19.2, U6.6 (ADR)
unnamed: D7.2 (DIN), R5.2
unnamed: R37.1, U8.11 (~SUSPEND)
unnamed: L1.1, R11.1
unnamed: C3.1, L1.2, R13.2
unnamed: D3.C (K), J3.9, Q6.3 (D)
unnamed: Q6.1 (G), R25.2, R32.2
unnamed: R36.2, U8.9 (~RST)
unnamed: R34.1, R35.2, U8.8 (VBUS)
unnamed: IO39.TP, U2.35 (IO39)
unnamed: Q2.1 (B), R38.2
unnamed: Q5.1 (B), R39.2
unnamed: J1.9, U16.3 (COMMON)
unnamed: Q1.1 (G), R23.2, R24.2
unnamed: J1.8, U16.4 (CONTACT_NO)
unnamed: J1.10, U16.2 (CONTACT_NC)
unnamed: D6.C (K), Q3.3 (D), U16.8 (COIL-)
unnamed: Q3.1 (G), R6.2, R31.2
unnamed: D1.2 (A), J2.1
unnamed: J4.A5 (CC1), R28.2
unnamed: D11.2, LEFT0.2, R12.1
unnamed: J4.B5 (CC2), R29.2
unnamed: D10.2, LEFT0.4, R14.1
unnamed: D13.1, R8.1, RIGHT0.2
unnamed: D12.1, R10.1, RIGHT0.4
PWR_N_MOSFET_AKTOR: R24.1, U2.32 (IO36)
PWR_N_MOSFET_SENSE: R25.1, U2.29 (IO34)
PWR_RELAI: R6.1, U2.34 (IO38)
RAK3172_RST: U2.19 (IO15)
RAK3172_RX: U2.15 (IO11)
RAK3172_TX: U2.14 (IO10)
SCL: J3.7, R18.1, U2.13 (IO9), U6.5 (SCL)
SDA: J3.6, R17.2, U2.12 (IO8), U6.4 (SDA)
SDI-12_ADC: J3.3, R11.2, U2.16 (IO12)
SENSE_MAX485_A: J3.4, R1.2, R2.2, U5.6 (A)
SENSE_MAX485_B: J3.5, R1.1, R3.2, U5.7 (B)
SENSE_MAX485_DE_RE: R33.1, U2.20 (IO16), U5.2 (~RE), U5.3 (DE)
U0_RXD: R4.1, U2.40 (RXD0)
U0_TXD: R27.1, U2.39 (TXD0)
U1_RXD: R12.2, RXD0.TP, U2.22 (IO18)
U1_TXD: R14.2, TXD0.TP, U2.21 (IO17)
U2_RXD: R8.2, U2.28 (IO33)
U2_TXD: R10.2, U2.38 (IO42)
U3_RXD: R41.1, U2.18 (IO14), U5.1 (RO)
U3_TXD: R40.1, U2.17 (IO13), U5.4 (DI)
USB_D+: D4.1, D-0.TP, J4.A6 (DP1), J4.B6 (DP2), U8.4 (D+)
USB_D-: D2.1, D+0.TP, J4.A7 (DN1), J4.B7 (DN2), U8.5 (D-)
WS2812_LED: R5.1, U2.30 (IO48)

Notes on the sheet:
MOSFETs
RELAI IN
+12V
PWR +12V GND
PWR GND
RS485 SENSOR
Use internal pull up resistor
SDA
MCP4725 & LM358 (0-10V)
+5V
RS485 B
RELAI CLOSED
GND
OUTPUT
SDI-12
ESP32 S3 MINI 1 N8
CP2102
CONNECTORS
INTERFACE
RELAI OPEN
POWER & BUCKET CONVERTER
PWM 0-10V
USB TYPE-C CONNECTOR
Max. 125VAC/ 1A Max. 30VDC/ 1A
IO, ADC, PWM, INT
ADC/ SDI-12
INPUT
RS485 A
SCL

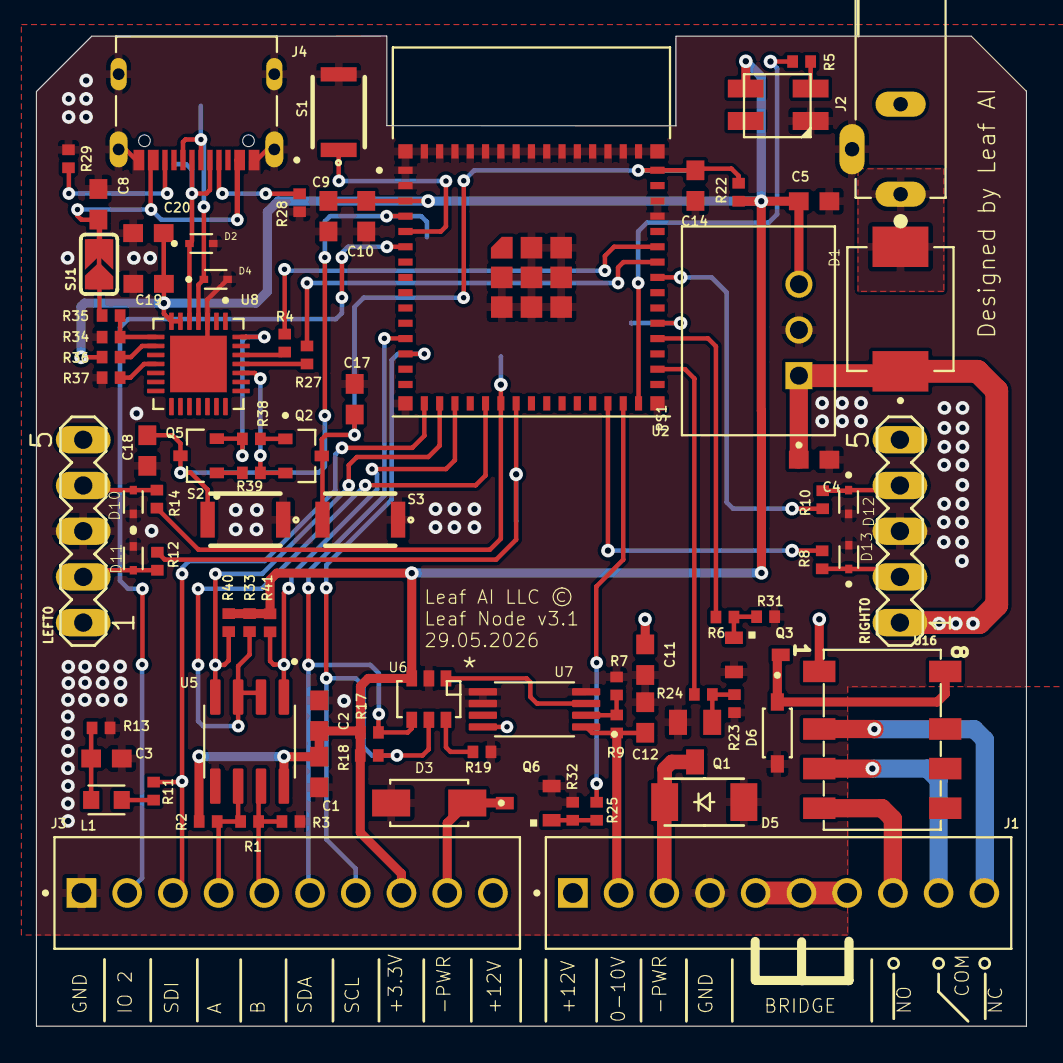
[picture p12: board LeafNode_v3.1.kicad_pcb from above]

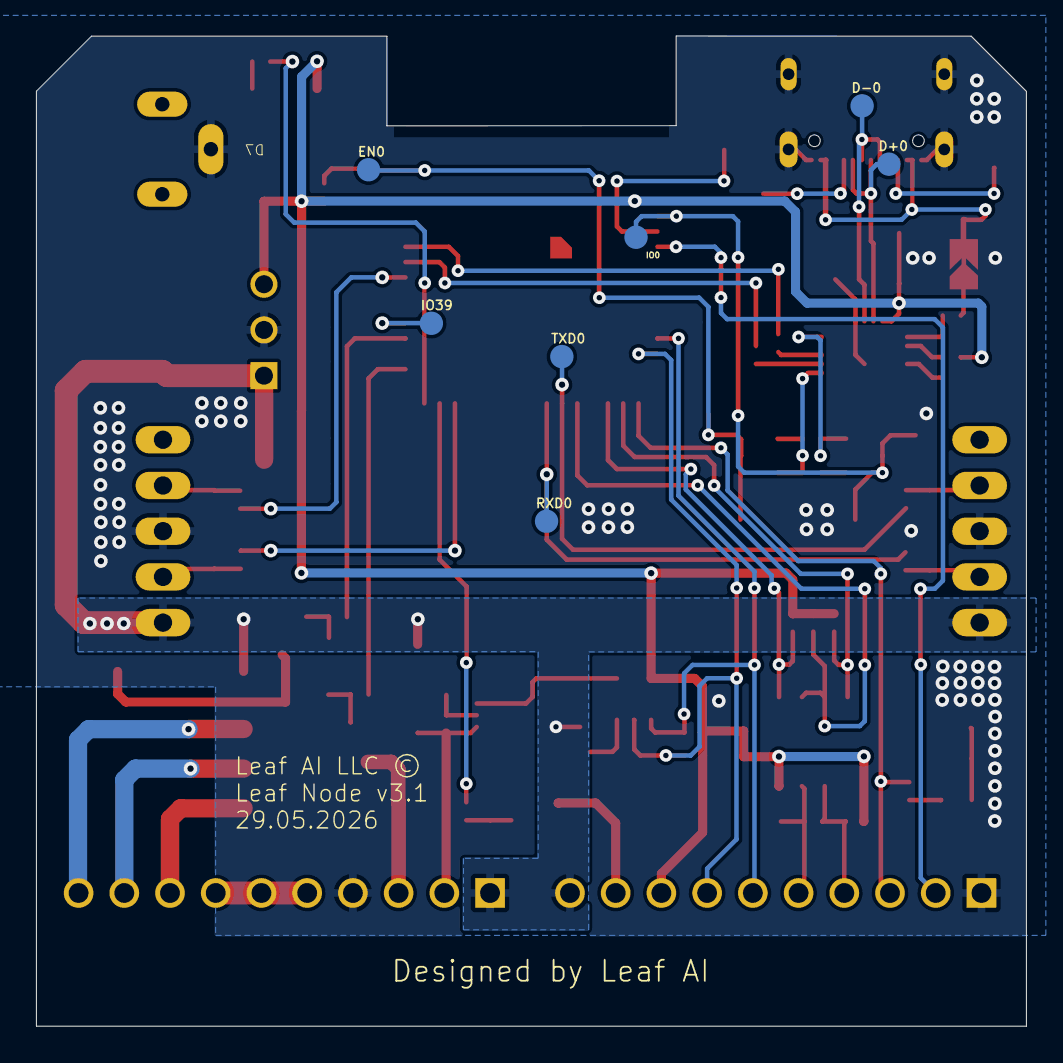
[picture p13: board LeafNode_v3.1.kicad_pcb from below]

Board: 2 copper layers, 55.0 x 55.0 mm, 91 parts (7 on the bottom side), 62 nets.

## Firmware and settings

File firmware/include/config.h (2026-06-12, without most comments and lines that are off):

#define CONFIG_H
#define FIRMWARE_VERSION            "1.19.3"
#define MANUFACTURER                "Leaf AI"
#define DEVICE_TYPE                 "LeafNode"
#define DEFAULT_DEVICE_NAME         "LeafNode"
#define BLE_DEVICE_KEY              "LeafNode2025"
#define HARDWARE_V3      // Uses WS2812B addressable LED (default)
    #define LED_WS2812B_PIN             48
    #define USE_WS2812B_LED             1
#define RS485_DE_RE_PIN             16      // DE/RE Direction control
#define RS485_RX_PIN                14      // Serial1 RX
#define RS485_TX_PIN                13      // Serial1 TX
#define UART_INPUT_RX_PIN           17      // Input port RX (from left neighbor)
#define UART_INPUT_TX_PIN           18      // Input port TX (to left neighbor)
#define UART_OUTPUT_RX_PIN          33      // Output port RX (from right neighbor)
#define UART_OUTPUT_TX_PIN          42      // Output port TX (to right neighbor)
#define UART_CHAIN_BAUD_RATE        115200  // Baud rate for chain communication
#define I2C_SDA_PIN                 8       // I2C Data
#define I2C_SCL_PIN                 9       // I2C Clock
#define SHT31_I2C_ADDRESS           0x44    // SHT31 Temperature & Humidity Sensor
#define EZOPH_I2C_ADDRESS           0x63    // EZO pH Sensor (99 decimal)
#define EZOEC_I2C_ADDRESS           0x64    // EZO EC Sensor (100 decimal)
#define MCP4725_I2C_ADDRESS         0x62    // MCP4725 12-bit DAC (default address, can be 0x61)
#define SDI12_DATA_PIN              12      // SDI-12 Data (single wire bidirectional)
#define SDI12_SENSOR_ADDRESS        '1'     // Default TEROS 12 sensor address
#define ONEWIRE_DATA_PIN            12      // OneWire Data (shared with SDI-12, manual bridge switch)
#define MOSFET_PIN                  36      // MOSFET control pin
#define RELAY_PIN                   38      // Relay control pin
#define PWM_IO2_PIN                 2       // PWM output on GPIO2
#define PWM_IO2_CHANNEL             3       // LEDC channel (0-2 used by RGB LED)
#define PWM_IO2_FREQUENCY           1000    // PWM frequency in Hz
#define PWM_IO2_RESOLUTION          10      // PWM resolution in bits (8=0-255, 10=0-1023, 12=0-4095)
#define PWM_IO2_MAX_VOLTAGE         3.3f    // Maximum output voltage (ESP32 logic level)
#define PWM_MOSFET_PIN              36      // PWM output on MOSFET gate (same as MOSFET_PIN)
#define PWM_MOSFET_CHANNEL          4       // LEDC channel (separate from IO2)
#define PWM_MOSFET_FREQUENCY        5000    // PWM frequency in Hz
#define PWM_MOSFET_RESOLUTION       10      // PWM resolution in bits (8=0-255, 10=0-1023, 12=0-4095)
#define PWM_MOSFET_MAX_VOLTAGE      10.0f   // Maximum output voltage (switched load voltage)
#define MQTT_TOPIC_PREFIX           "lai/devices/"
#define MQTT_TOPIC_REGISTER         "/register"
#define MQTT_TOPIC_REGISTER_ACK     "/registration_ack"
#define MQTT_TOPIC_STATUS           "/status"
#define MQTT_TOPIC_HEARTBEAT        "/heartbeat"
#define MQTT_TOPIC_COMMAND          "/command"
#define MQTT_TOPIC_COMMAND_RESPONSE "/command_response"
#define MQTT_TOPIC_COMMANDS         "/commands"         // Legacy
#define MQTT_SENSOR_PREFIX          "sensors/"
#define MQTT_SENSOR_DATA            "/data"
#define MQTT_DEFAULT_PORT           1883
#define MQTT_KEEPALIVE              60                  // Seconds
#define MQTT_RECONNECT_DELAY        5000                // ms
#define MQTT_BUFFER_SIZE            1024                // bytes
#define DNS_MAX_FAILURES_BEFORE_RESTART  5              // System restart after X DNS failures
#define HEARTBEAT_INTERVAL          60000               // 60 seconds
#define WATCHDOG_TIMEOUT            60000               // 60 seconds
#define CONFIG_SAVE_INTERVAL        300000              // 5 minutes
#define LED_UPDATE_INTERVAL         50                  // 50ms
#define SETUP_TIMEOUT               30000               // 30 seconds
#define NETWORK_TIMEOUT             10000               // 10 seconds
#define WIFI_MAX_RETRY              3                   // Max retry attempts
#define WIFI_RETRY_DELAY            5000                // 5 seconds between retries
#define WIFI_CONNECTION_TIMEOUT     30000               // 30 seconds
#define SENSOR_READING_INTERVAL     30000               // 30 seconds default
#define SENSOR_MAX_CONSECUTIVE_ERRORS   5               // Max errors before backoff
#define SENSOR_BASE_BACKOFF_INTERVAL    60000           // 1 minute base backoff
#define SENSOR_MAX_BACKOFF_INTERVAL     600000          // 10 minutes max backoff
#define STACK_SIZE_DEFAULT          4096
#define STACK_SIZE_LARGE            8192
#define JSON_BUFFER_SIZE            1024
#define JSON_BUFFER_SIZE_LARGE      2048
#define MAX_DEVICE_NAME_LENGTH      32
#define MAX_SERIAL_NUMBER_LENGTH    32
#define MAX_SSID_LENGTH             32
#define MAX_PASSWORD_LENGTH         64
#define MAX_MQTT_SERVER_LENGTH      64
#define MAX_MQTT_USERNAME_LENGTH    32
#define MAX_MQTT_PASSWORD_LENGTH    64
#define NVS_NAMESPACE               "leafnode"
#define NVS_CONFIG_KEY              "config"
#define NVS_MAX_CONFIG_SIZE         4000                // bytes
#define DEBUG_SERIAL                true
#define SERIAL_BAUD_RATE            115200
#define FACTORY_WEBSERVER_PORT      80
    #define DEFAULT_LOG_LEVEL       "DEBUG"
    #define ENABLE_DEBUG_LOGS       true
    #define ENABLE_VERBOSE_MQTT     true

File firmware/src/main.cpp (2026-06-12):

#include <Arduino.h>
#include "LeafNode.h"

// Global instance of LeafNode
LeafNode* leafNode = nullptr;

void setup() {
    // Create LeafNode instance
    leafNode = new LeafNode();
    
    // Initialize the system
    if (!leafNode->initialize()) {
        Serial.println("FATAL: LeafNode initialization failed!");
        Serial.println("System will restart in 5 seconds...");
        delay(5000);
        ESP.restart();
    }
    
    Serial.println("LeafNode initialized successfully!");
}

void loop() {
    if (leafNode) {
        leafNode->update();
    }
    
    // Small delay to prevent overwhelming the system
    delay(1);
}

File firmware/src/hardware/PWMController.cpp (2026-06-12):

#include "PWMController.h"
#include "config.h"

// Logger helper macros - use Serial if logger is nullptr
#define LOG_INFO(tag, msg) if (logger_) logger_->info(tag, msg); else Serial.println("[" + String(tag) + "] " + msg)
#define LOG_ERROR(tag, msg) if (logger_) logger_->error(tag, msg); else Serial.println("[" + String(tag) + "] ERROR: " + msg)
#define LOG_WARNING(tag, msg) if (logger_) logger_->warning(tag, msg); else Serial.println("[" + String(tag) + "] WARNING: " + msg)
#define LOG_DEBUG(tag, msg) if (logger_) logger_->debug(tag, msg); else Serial.println("[" + String(tag) + "] DEBUG: " + msg)

PWMController::PWMController(Logger* logger) 
    : logger_(logger)
    , pin_(2)
    , channel_(3)
    , frequency_(5000)
    , resolution_(8)
    , maxValue_(255)
    , currentValue_(0)
    , initialized_(false)
    , ledUpdateCallback_(nullptr)
    , lastCommandType_("")
    , timerActive_(false)
    , timerEndMillis_(0) {
}

PWMController::~PWMController() {
    if (initialized_) {
        turnOff();  // Safety: Turn off PWM on destruction
        ledcDetachPin(pin_);
    }
}

bool PWMController::initialize(uint8_t pin, uint8_t channel, uint32_t frequency, uint8_t resolution) {
    if (initialized_) {
        LOG_INFO("PWMController", "Already initialized");
        return true;
    }
    
    pin_ = pin;
    channel_ = channel;
    frequency_ = frequency;
    resolution_ = resolution;
    maxValue_ = (1 << resolution_) - 1;  // 2^resolution - 1
    
    LOG_INFO("PWMController", "Initializing PWM on GPIO" + String(pin_) + 
             " (Channel " + String(channel_) + ", " + String(frequency_) + "Hz, " + 
             String(resolution_) + "-bit)");
    
    // Setup LEDC channel
    ledcSetup(channel_, frequency_, resolution_);
    
    // Attach pin to channel
    ledcAttachPin(pin_, channel_);
    
    // Set to 0 as safe default
    writePWM(0);
    
    initialized_ = true;
    
    LOG_INFO("PWMController", "PWM Controller initialized successfully (0-" + String(maxValue_) + ")");
    
    return true;
}

bool PWMController::setValue(uint16_t value) {
    if (!initialized_) {
        LOG_ERROR("PWMController", "Not initialized");
        return false;
    }
    
    value = clampValue(value);
    
    if (writePWM(value)) {
        currentValue_ = value;
        lastCommandType_ = "value";
        
        LOG_INFO("PWMController", "Set PWM value: " + String(value) + 
                 " (" + String(getCurrentPercent(), 1) + "%)");
        
        // Trigger LED update callback if set
        if (ledUpdateCallback_) {
            ledUpdateCallback_();
        }
        
        return true;
    }
    
    return false;
}

bool PWMController::setPercent(float percent) {
    if (!initialized_) {
        LOG_ERROR("PWMController", "Not initialized");
        return false;
    }
    
    // Clamp percentage to 0-100
    if (percent < 0.0f) percent = 0.0f;
    if (percent > 100.0f) percent = 100.0f;
    
    // Convert percentage to value
    uint16_t value = (uint16_t)((percent / 100.0f) * maxValue_);
    
    if (writePWM(value)) {
        currentValue_ = value;
        lastCommandType_ = "percent";
        
        LOG_INFO("PWMController", "Set PWM percent: " + String(percent, 1) + 
                 "% (value: " + String(value) + ")");
        
        // Trigger LED update callback if set
        if (ledUpdateCallback_) {
            ledUpdateCallback_();
        }
        
        return true;
    }
    
    return false;
}

bool PWMController::setVoltage(float voltage) {
    if (!initialized_) {
        LOG_ERROR("PWMController", "Not initialized");
        return false;
    }
    
    // Determine max voltage based on pin configuration
    float maxVoltage = 3.3f;  // Default ESP32 logic level
    #ifdef PWM_IO2_MAX_VOLTAGE
    if (pin_ == PWM_IO2_PIN) {
        maxVoltage = PWM_IO2_MAX_VOLTAGE;
    }
    #endif
    #ifdef PWM_MOSFET_MAX_VOLTAGE
    if (pin_ == PWM_MOSFET_PIN) {
        maxVoltage = PWM_MOSFET_MAX_VOLTAGE;
    }
    #endif
    
    // Clamp voltage to valid range
    if (voltage < 0.0f) voltage = 0.0f;
    if (voltage > maxVoltage) voltage = maxVoltage;
    
    // Convert voltage to value
    uint16_t value = (uint16_t)((voltage / maxVoltage) * maxValue_);
    
    if (writePWM(value)) {
        currentValue_ = value;
        lastCommandType_ = "voltage";
        
        LOG_INFO("PWMController", "Set PWM voltage: " + String(voltage, 2) + 
                 "V (value: " + String(value) + ")");
        
        // Trigger LED update callback if set
        if (ledUpdateCallback_) {
            ledUpdateCallback_();
        }
        
        return true;
    }
    
    return false;
}

bool PWMController::turnOff() {
    if (!initialized_) {
        LOG_ERROR("PWMController", "Not initialized");
        return false;
    }
    
    if (writePWM(0)) {
        currentValue_ = 0;
        lastCommandType_ = "off";
        
        // Cancel any active timer
        timerActive_ = false;
        timerEndMillis_ = 0;
        
        LOG_INFO("PWMController", "PWM turned off");
        
        // Trigger LED update callback if set
        if (ledUpdateCallback_) {
            ledUpdateCallback_();
        }
        
        return true;
    }
    
    return false;
}

bool PWMController::setValueWithDuration(uint16_t value, uint32_t durationMillis) {
    if (!setValue(value)) {
        return false;
    }
    
    // Setup timer if duration is specified
    if (durationMillis > 0) {
        timerActive_ = true;
        timerEndMillis_ = millis() + durationMillis;
        LOG_INFO("PWMController", "Timer set for " + String(durationMillis) + "ms");
    } else {
        timerActive_ = false;
        timerEndMillis_ = 0;
    }
    
    return true;
}

bool PWMController::setPercentWithDuration(float percent, uint32_t durationMillis) {
    if (!setPercent(percent)) {
        return false;
    }
    
    // Setup timer if duration is specified
    if (durationMillis > 0) {
        timerActive_ = true;
        timerEndMillis_ = millis() + durationMillis;
        LOG_INFO("PWMController", "Timer set for " + String(durationMillis) + "ms");
    } else {
        timerActive_ = false;
        timerEndMillis_ = 0;
    }
    
    return true;
}

bool PWMController::setVoltageWithDuration(float voltage, uint32_t durationMillis) {
    if (!setVoltage(voltage)) {
        return false;
    }
    
    // Setup timer if duration is specified
    if (durationMillis > 0) {
        timerActive_ = true;
        timerEndMillis_ = millis() + durationMillis;
        LOG_INFO("PWMController", "Timer set for " + String(durationMillis) + "ms");
    } else {
        timerActive_ = false;
        timerEndMillis_ = 0;
    }
    
    return true;
}
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

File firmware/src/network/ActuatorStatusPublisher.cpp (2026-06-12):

#include "ActuatorStatusPublisher.h"
#include "../hardware/MCP4725.h"
#include "../hardware/PWMController.h"
#include "config.h"

ActuatorStatusPublisher::ActuatorStatusPublisher(RuntimeConfig* config, MQTTManager* mqttManager, 
                                                 Logger* logger, Actuator* actuator, MCP4725* mcp4725,
                                                 PWMController* pwmController, PWMController* pwmControllerMOSFET)
    : config_(config), mqttManager_(mqttManager), logger_(logger), actuator_(actuator), mcp4725_(mcp4725),
      pwmController_(pwmController), pwmControllerMOSFET_(pwmControllerMOSFET) {
}

ActuatorStatusPublisher::~ActuatorStatusPublisher() {
}

bool ActuatorStatusPublisher::publishStatus(const String& lastCommand, const String& lastTarget, 
                                           const String& lastTimestamp, const String& actuatorType,
                                           bool isRamping, float rampTargetValue, 
                                           uint32_t rampDurationSeconds, uint32_t rampElapsedSeconds) {
    if (!mqttManager_) {
        if (logger_) {
            logger_->error("ActuatorStatusPublisher", "MQTT manager not available");
        }
        return false;
    }
    
    if (!actuator_) {
        if (logger_) {
            logger_->error("ActuatorStatusPublisher", "Actuator not available");
        }
        return false;
    }
    
    String topic = getStatusTopic();
    String payload = buildStatusPayload(lastCommand, lastTarget, lastTimestamp, actuatorType,
                                       isRamping, rampTargetValue, rampDurationSeconds, rampElapsedSeconds);
    
    if (topic.isEmpty() || payload.isEmpty()) {
        if (logger_) {
            logger_->error("ActuatorStatusPublisher", "Empty topic or payload");
        }
        return false;
    }
    
    if (logger_) {
        logger_->info("ActuatorStatusPublisher", "Publishing actuator status to: " + topic);
        logger_->debug("ActuatorStatusPublisher", "Payload: " + payload);
    }
    
    bool result = mqttManager_->publish(topic, payload, false);
    
    if (result) {
        if (logger_) {
            logger_->info("ActuatorStatusPublisher", "Actuator status published successfully");
        }
    } else {
        if (logger_) {
            logger_->error("ActuatorStatusPublisher", "Failed to publish actuator status");
        }
    }
    
    return result;
}

String ActuatorStatusPublisher::getStatusTopic() const {
    if (!config_ || config_->getSerialNumber().isEmpty()) {
        if (logger_) {
            logger_->error("ActuatorStatusPublisher", "Serial number not configured");
        }
        return "";
    }
    
    // Topic format: lai/devices/{serial}/status
    return "lai/devices/" + config_->getSerialNumber() + "/status";
}

String ActuatorStatusPublisher::buildStatusPayload(const String& lastCommand, const String& lastTarget, 
                                                   const String& lastTimestamp, const String& actuatorType,
                                                   bool isRamping, float rampTargetValue, 
                                                   uint32_t rampDurationSeconds, uint32_t rampElapsedSeconds) {
    DynamicJsonDocument doc(1024);
    
    // Device section
    JsonObject device = doc.createNestedObject("device");
    device["serial"] = config_ ? config_->getSerialNumber() : "UNKNOWN";
    device["name"] = "Leaf Node";
    device["firmware"] = FIRMWARE_VERSION;
    device["uptime"] = millis() / 1000;  // Convert to seconds
    
    // Network section
    JsonObject network = doc.createNestedObject("network");
    network["wifi_ssid"] = WiFi.SSID();
    network["ip_address"] = WiFi.localIP().toString();
    network["rssi"] = WiFi.RSSI();
    network["mac_address"] = WiFi.macAddress();
    
    // Only include the specific actuator type that changed, or both if not specified
    bool includeMosfet = actuatorType.isEmpty() || actuatorType.equalsIgnoreCase("mosfet");
    bool includeRelay = actuatorType.isEmpty() || actuatorType.equalsIgnoreCase("relay");
    
    // MOSFET section (only if relevant)
    if (includeMosfet) {
        JsonObject mosfet = doc.createNestedObject("mosfet");
        mosfet["state"] = actuator_ ? actuator_->getState(Actuator::Type::MOSFET) : false;
        if (actuator_ && actuator_->isTimerActive(Actuator::Type::MOSFET)) {
            mosfet["timer_active"] = true;
            uint32_t remainingMillis = actuator_->getRemainingMillis(Actuator::Type::MOSFET);
            
            mosfet["timer_remaining_ms"] = remainingMillis;
        } else {
            mosfet["timer_active"] = false;
        }
    }
    
    // Relay section (only if relevant)
    if (includeRelay) {
        JsonObject relay = doc.createNestedObject("relay");
        relay["state"] = actuator_ ? actuator_->getState(Actuator::Type::RELAY) : false;
        if (actuator_ && actuator_->isTimerActive(Actuator::Type::RELAY)) {
            relay["timer_active"] = true;
            uint32_t remainingMillis = actuator_->getRemainingMillis(Actuator::Type::RELAY);
            
            relay["timer_remaining_ms"] = remainingMillis;
        } else {
            relay["timer_active"] = false;
        }
    }
    
    // DAC section (if available and DAC-related actuatorType OR general status)
    bool isDACStatus = actuatorType.equalsIgnoreCase("dac") || 
                       actuatorType.startsWith("dac_") ||
                       isRamping ||
                       actuatorType.isEmpty(); // Include DAC in general status
    if (mcp4725_ && isDACStatus) {
        JsonObject dac = doc.createNestedObject("dac");
        dac["value"] = mcp4725_->getCurrentValue();
        dac["voltage"] = mcp4725_->getCurrentVoltage();
        dac["percent"] = mcp4725_->getCurrentPercent();
        dac["last_command_type"] = mcp4725_->getLastCommandType();
        
        // Add ramping info if active
        if (isRamping) {
            dac["ramping"] = true;
            dac["ramp_duration_seconds"] = rampDurationSeconds;
            dac["ramp_elapsed_seconds"] = rampElapsedSeconds;
            
            // Add target value based on last command type
            String commandType = mcp4725_->getLastCommandType();
            if (commandType == "voltage") {
                dac["ramp_target_voltage"] = rampTargetValue;
            } else if (commandType == "percent") {
                dac["ramp_target_percent"] = rampTargetValue;
            } else if (commandType == "value") {
                dac["ramp_target_value"] = (uint16_t)rampTargetValue;
            }
        }
    }
    
    // PWM section (if available and PWM-related actuatorType OR general status)
    bool isPWMStatus = actuatorType.equalsIgnoreCase("pwm") || 
                       actuatorType.startsWith("pwm_") ||
                       actuatorType.isEmpty(); // Include PWM in general status
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

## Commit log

2026-06-15 Clean schematic
    [LeafNode_v3.1.kicad_sch]
2026-07-30 Updated BOM for JLCPCB
    [Node-v3.1-BOM_JLCSMT .xlsx]
